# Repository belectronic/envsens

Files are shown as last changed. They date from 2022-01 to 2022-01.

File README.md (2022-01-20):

# EnvSens

EnvSens is a compact sensor module for ambient air and brightness monitoring with an ESP-12E Wifi microcontroller.
It runs until a minimal battery voltage from 2.5 V properly. Ideal for IoT applications!

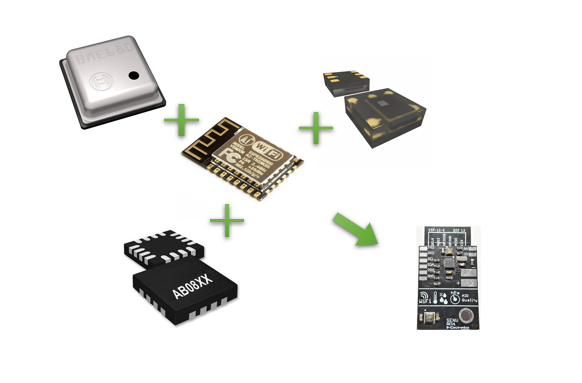
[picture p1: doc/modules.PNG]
Modules


With help of the BME680 sensor from Bosch, temperature, humidity, air pressure and air quality can be measured in a very energy-saving way.
In addition, LITE-ON's LTR303 digital ambient light sensor enables the monitoring of daylight and lamp light close to the spectral viewing range.
A real-time clock (RTC) AB0805 from Abracon provides the time for the measuring points with low power consumption.
All modules are connected to ESP-12E via I2C bus.

---

## Hardware

| Module | Function | Datasheet | Software Library |
| - | - | - | - |
| Bosch BME680 | Temperature, Humidity, Pressure, Air Quality | [bst-bme680-ds001.pdf](https://www.bosch-sensortec.com/media/boschsensortec/downloads/datasheets/bst-bme680-ds001.pdf) | [Adafruit_BME680](https://github.com/adafruit/Adafruit_BME680) |
| LITE-ON LTR303 | Ambient Light Sensor | [Lite-On_LTR-303ALS-01_DS.pdf](https://www.mouser.com/datasheet/2/239/Lite-On_LTR-303ALS-01_DS_ver%201.1-1175269.pdf)| [Automote_LTR303](https://github.com/automote/LTR303) |
| Abracon AB0805 | RTC | [AB08X5-RTC.PDF](https://abracon.com/Precisiontiming/AB08X5-RTC.PDF ) | [AB0805_lib (*)](https://github.com/curransinha/AB0805_lib) |
| AI-Thinker ESP-12E | 32 Bit Microcontroller with WiFi | [ESP12E_Datasheet.pdf](https://components101.com/sites/default/files/component_datasheet/ESP12E%20Datasheet.pdf) |
| * Issue in Abracon AB0805 Library: Hours shows 0 every time. Resolution -> Remove all functions for 12-hour format (see issues discussions) |

---

## Pinout

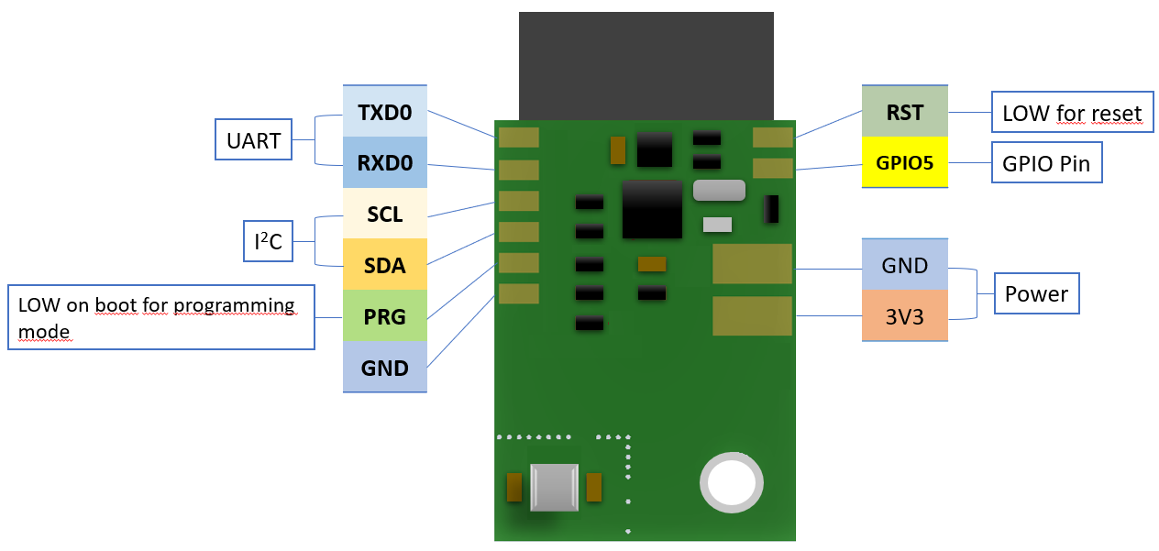
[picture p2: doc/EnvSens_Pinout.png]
Pinout


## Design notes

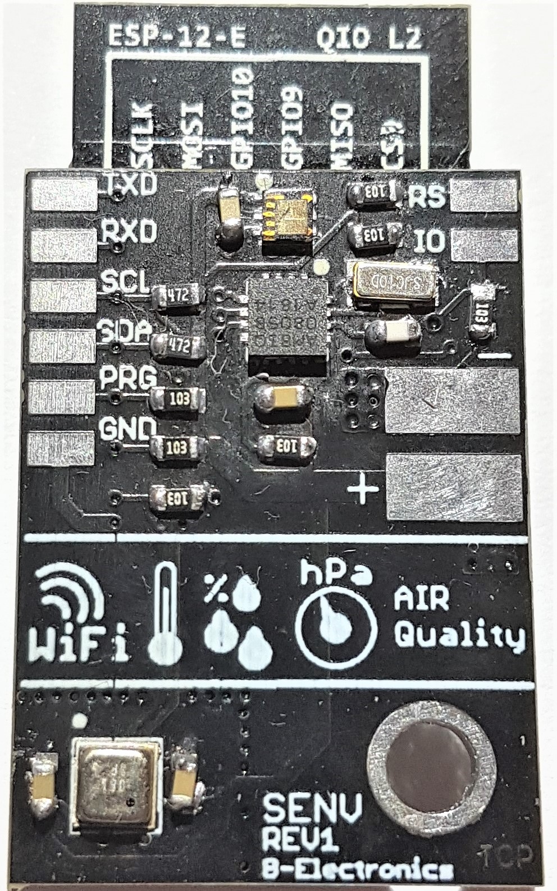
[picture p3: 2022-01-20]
doc/envsens1.jpg

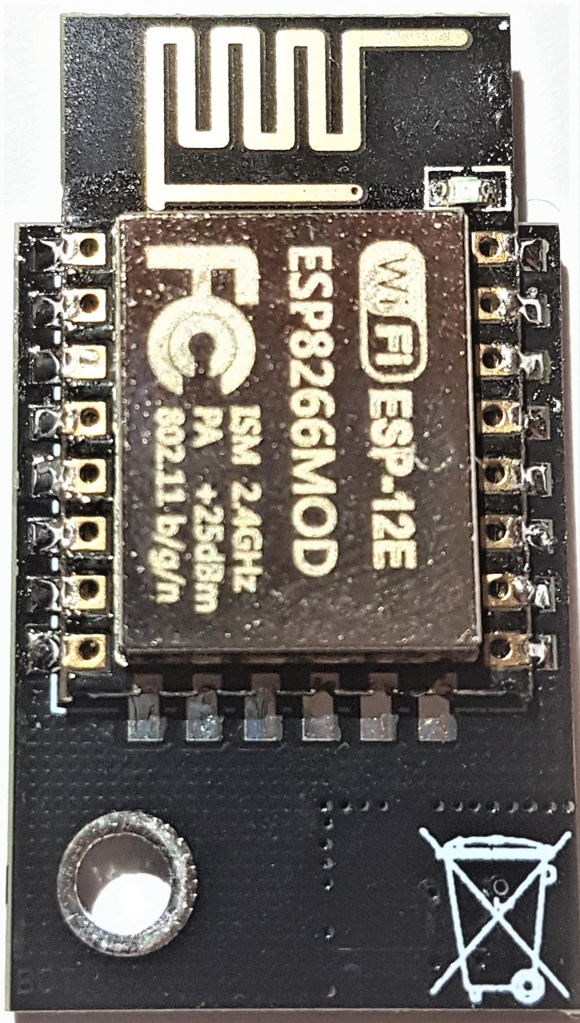
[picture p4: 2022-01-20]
doc/envsens2.jpg

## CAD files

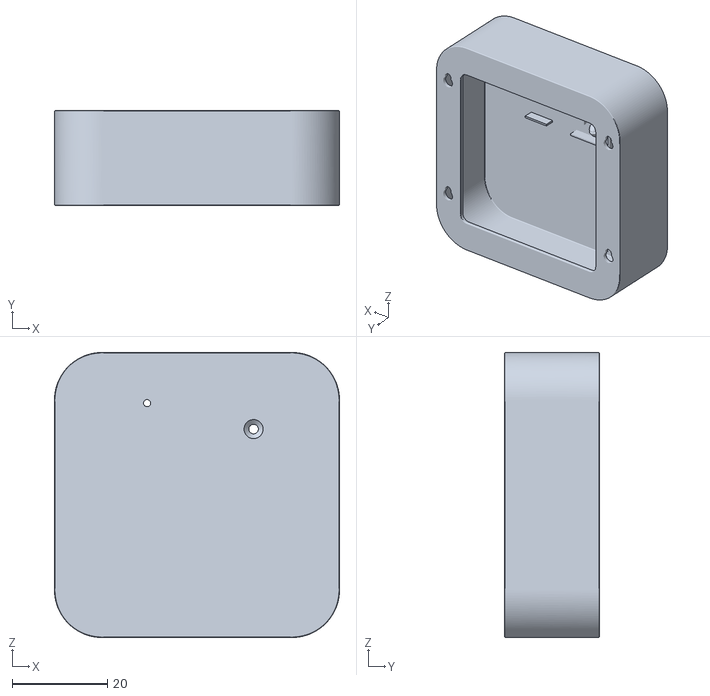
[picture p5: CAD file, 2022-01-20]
CAD/housing_new.stl
60.0 x 20.0 x 60.0

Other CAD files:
CAD/housing_holder.f3d
CAD/housing_new.ipt

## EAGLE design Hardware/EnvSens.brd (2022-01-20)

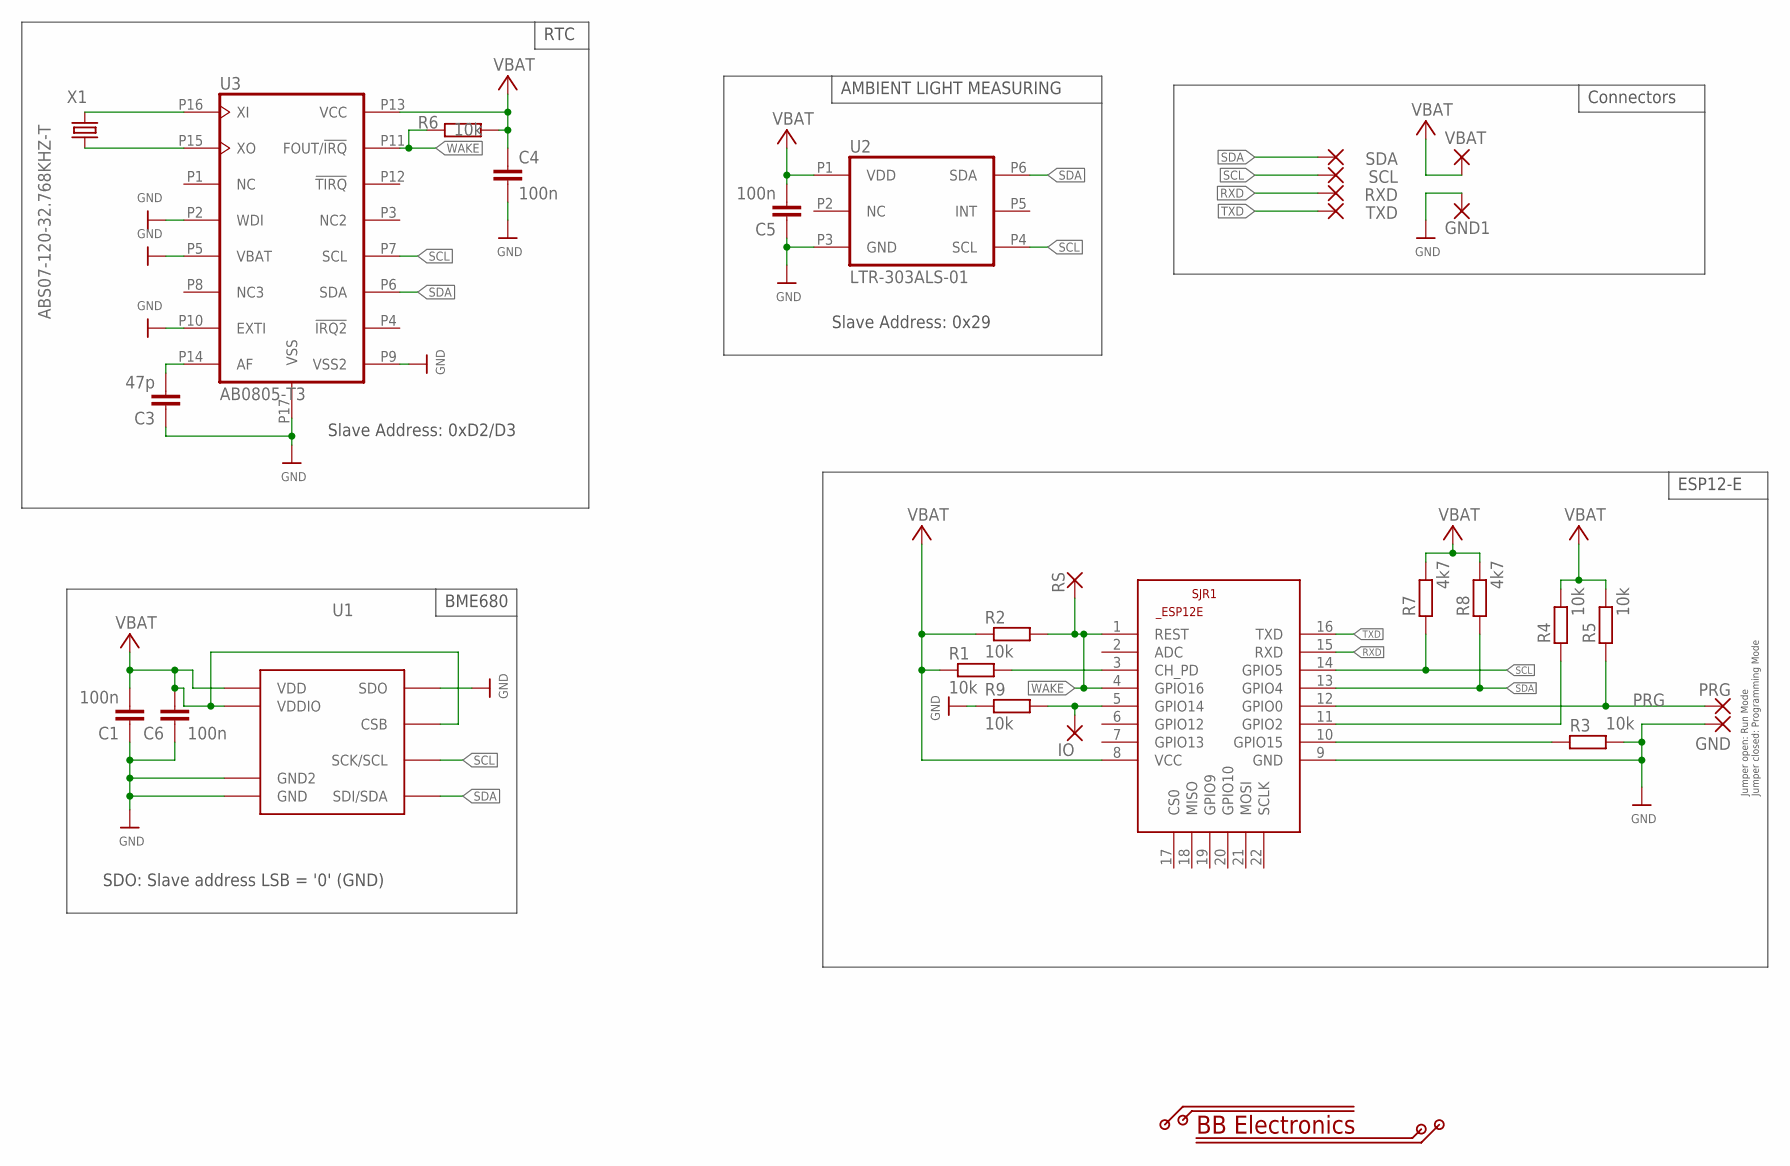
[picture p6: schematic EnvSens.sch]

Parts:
C1, C4, C5, C6: 100n; 0603
C3: 47p; 0603
GND: SMD2; SMD1,27-2,54
GND1: SMD5; SMD2,54-5,08
IO: SMD2; SMD1,27-2,54
PRG: SMD2; SMD1,27-2,54
R1, R2, R3, R4, R5, R6, R9: 10k; 0603
R7, R8: 4k7; 0603
RS: SMD2; SMD1,27-2,54
RXD: SMD2; SMD1,27-2,54
SCL: SMD2; SMD1,27-2,54
SDA: SMD2; SMD1,27-2,54
SJR1: ESP8266-12EESP12E; ESP8266-ESP12E
TXD: SMD2; SMD1,27-2,54
U1: BME680
U2: LTR-303ALS-01; 6-DFN
U3: AB0805-T3; 16-VFQFN
VBAT: SMD5; SMD2,54-5,08
X1: ABS07-120-32.768KHZ-T

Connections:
GND: C1.P1 (1), C3.P1 (1), C4.P2 (2), C5.P1 (1), C6.P1 (1), GND.1, GND1.1, R3.P2 (2), R9.P1 (1), SJR1.9 (GND), U1.P1 (GND), U1.P5 (SDO), U1.P7 (GND2), U2.P3 (GND), U3.P2 (WDI), U3.P5 (VBAT), U3.P9 (VSS2), U3.P10 (EXTI), U3.P17 (VSS)
GPIO: IO.1, R9.P2 (2), SJR1.5 (GPIO14)
unnamed: R1.P2 (2), SJR1.3 (CH_PD)
unnamed: R3.P1 (1), SJR1.10 (GPIO15)
unnamed: R4.P1 (1), SJR1.11 (GPIO2)
unnamed: C3.P2 (2), U3.P14 (AF)
unnamed: U3.P16 (XI), X1.P2 (2)
unnamed: U3.P15 (XO), X1.P1 (1)
PRG: PRG.1, R5.P1 (1), SJR1.12 (GPIO0)
RXD: RXD.1, SJR1.15 (RXD)
SCL: R7.P1 (1), SCL.1, SJR1.14 (GPIO5), U1.P4 (SCK/SCL), U2.P4 (SCL), U3.P7 (SCL)
SDA: R8.P1 (1), SDA.1, SJR1.13 (GPIO4), U1.P3 (SDI/SDA), U2.P6 (SDA), U3.P6 (SDA)
TXD: SJR1.16 (TXD), TXD.1
VBAT: C1.P2 (2), C4.P1 (1), C5.P2 (2), C6.P2 (2), R1.P1 (1), R2.P1 (1), R4.P2 (2), R5.P2 (2), R6.P2 (2), R7.P2 (2), R8.P2 (2), SJR1.8 (VCC), U1.P2 (CSB), U1.P6 (VDDIO), U1.P8 (VDD), U2.P1 (VDD), U3.P13 (VCC), VBAT.1
WAKE: R2.P2 (2), R6.P1 (1), RS.1, SJR1.1 (REST), SJR1.4 (GPIO16), U3.P11 (FOUT/!IRQ!)

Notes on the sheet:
SDO: Slave address LSB = '0' (GND)
Jumper open: Run Mode Jumper closed: Programming Mode
BME680
RTC
AMBIENT LIGHT MEASURING
Connectors
ESP12-E
Slave Address: 0xD2/D3
Slave Address: 0x29

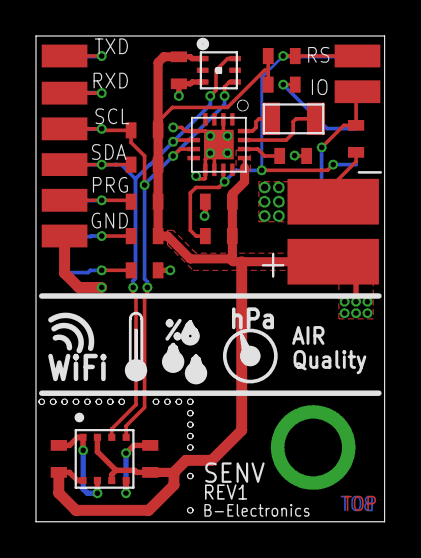
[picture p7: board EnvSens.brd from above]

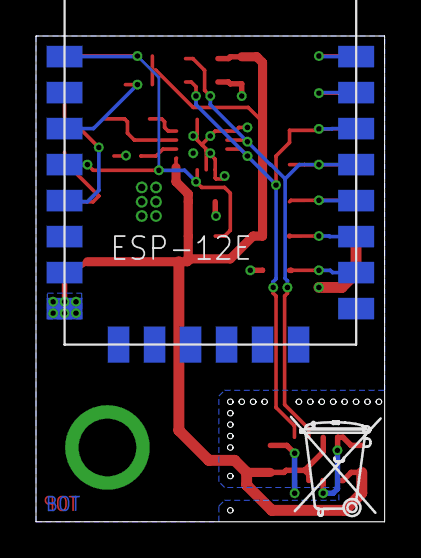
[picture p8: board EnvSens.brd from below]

Board: 2 copper layers, 19.4 x 27.0 mm, 30 parts (2 on the bottom side), 15 nets.

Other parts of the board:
U$5: TONNE_10.00

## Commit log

2022-01-20 Add all files
    [EnvSens.brd, EnvSens.sch, housing_holder.f3d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]
2022-01-20 Fix wake up issue
    [EnvSens.brd]
